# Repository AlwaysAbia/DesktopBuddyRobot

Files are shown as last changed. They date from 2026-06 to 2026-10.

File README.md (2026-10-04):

# Desktop Buddy Robot

A desktop robot with a circular addressable-LED "eye" driven by an ESP32.

The 76-LED display has three modes: the eye animation (default), an a scrolling digital clock (time from NTP) (time from NTP) and a scrolling history of the last 3 messages. The text is tilted 45 degrees so it lines up with the LED grid; rotate the robot about 45 degrees clockwise to read it. The companion app switches modes, eye color and WiFi over Bluetooth LE (GATT layout in [`interface-contract.md`](interface-contract.md)); the eye and Bluetooth work without WiFi. The temporary ThingsBoard RPCs in the same file remain for remote testing.

## Repository layout

| Folder | Contents | Tool |
|---|---|---|
| `BuddyBotFirmware/` | ESP32 firmware (eye animation, WiFi, OTA) | PlatformIO |
| `BuddyRobotDisplay/` | LED display PCB (schematics, layout, libraries, OutJob) | Altium Designer |
| `BuddyRobot3DModel/` | Enclosure CAD and printable STLs | Autodesk Inventor |

Interfaces shared between firmware, the mobile app and the server are documented in
[`interface-contract.md`](interface-contract.md).

## Firmware quick start

1. Install [PlatformIO](https://platformio.org/) (VS Code extension or CLI).
2. Copy `BuddyBotFirmware/include/secrets.example.h` to `BuddyBotFirmware/include/secrets.h` and fill in your ThingsBoard access token and, for the very first boot only, your WiFi credentials (after that WiFi is set over Bluetooth and kept in NVS).
3. From `BuddyBotFirmware/`:
   - Build: `pio run`
   - Flash over USB (first flash / recovery): `pio run -t upload`
   - Over-the-air updates: upload `.pio/build/esp32dev/firmware.bin` as a ThingsBoard OTA package (see `interface-contract.md`, section 3)
   - Serial monitor: `pio device monitor`

## License

MIT, see [LICENSE](LICENSE).

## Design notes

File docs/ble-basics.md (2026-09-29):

# BLE basics for this project

Plain-language notes on the Bluetooth terms that come up when testing the robot.
The exact UUIDs and payloads are in [../interface-contract.md](../interface-contract.md), section 1.

## BLE vs "Bluetooth" in the phone settings

Bluetooth Low Energy (BLE) is a different mode from classic Bluetooth (headphones, speakers,
keyboards). The phone's Bluetooth settings screen mostly handles classic devices. The robot
shows up there because it advertises, but connecting to it needs an app that speaks BLE
(nRF Connect for testing, the companion app later).

## GATT

**GATT** (Generic Attribute Profile) is how a BLE device lays out its data so that any phone can
read and write it.

- A **service** is a group of related values. The robot has one, `9b370000-…`.
- A **characteristic** is one value inside a service that the phone can read, write, or
  subscribe to. The robot has five: WiFi Config, Eye Color, Mode Select, OTA Check Trigger, Status.
- A **UUID** is the long ID that names a service or characteristic. Custom ones like ours have no
  official name, so tools show "Unknown" unless the device also provides a description (the
  robot does, since 0.5.1).
- **Properties** say what the phone may do with a characteristic: Read, Write, Notify.
- **Notify** means the robot pushes a new value to the phone by itself, after the phone has
  subscribed (the triple-arrow button in nRF Connect). Only Status has it.

The robot is the GATT **server** (it holds the data); the phone is the **client** (it asks for
and sets values).

## MTU

**MTU** (Maximum Transmission Unit) is the largest single message a BLE connection carries. Every
connection starts at 23 bytes, which leaves 20 bytes of actual data (3 bytes are protocol
overhead). The phone and robot can agree on a bigger one, and the phone must ask for it:

- nRF Connect on Android: three-dot menu on the connected device, **Request MTU**, enter `247`.
- iOS negotiates it automatically.

Why it matters here: the Status JSON is about 100 bytes and a WiFi Config write can be about
100 bytes. At the default MTU, notifications of that size do not fit. The robot then skips the
notification instead of sending it cut off, so Status only changed when you pressed Read (a Read
is split across several messages automatically). With MTU 247 the notifications arrive.
The companion app must request an MTU of at least 128 right after connecting.

## Pairing

The robot uses "Just Works" pairing: no PIN, and nothing is remembered on the robot. Only the
WiFi Config write asks the phone for an encrypted link, which is why the pairing prompt appears
the first time you write the WiFi credentials.

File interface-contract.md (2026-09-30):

# Interface Contract — Desktop Robot

This is the single source of truth for every interface that crosses a
firmware / mobile app / server boundary. Whenever a Claude Code session
defines or changes a UUID, NVS key, RPC method, or attribute name, **update
this file in the same session**, before finishing. Later sessions (especially
the Flutter app session) are built directly against what's written here.

Keep this file at the repository root (shared by firmware, mobile app and
server) so every session can find it.

---

## 1. BLE GATT Service (Firmware ↔ Mobile App)

**Defined in:** Session D (Phase 2b). Implemented in firmware 0.5.0 (`BuddyBotFirmware/src/ble_control.cpp`).

- Advertised device name: `BuddyBot` (in the scan response). The service UUID is in the advertising packet, so scan by UUID.
- Role: the robot is the GATT peripheral/server; the app is the central. One client at a time; advertising resumes after a disconnect.
- Service UUID: `9b370000-a32f-4baf-8406-88e9298fd20d`

| Characteristic | UUID | Properties | Payload |
|---|---|---|---|
| WiFi Config | `9b370001-a32f-4baf-8406-88e9298fd20d` | Write (encrypted link required) | UTF-8 JSON, see below |
| Eye Color | `9b370002-a32f-4baf-8406-88e9298fd20d` | Read, Write | 1 byte, `0`–`3` |
| Mode Select | `9b370003-a32f-4baf-8406-88e9298fd20d` | Read, Write | 1 byte, `0`–`2` |
| OTA Check Trigger | `9b370004-a32f-4baf-8406-88e9298fd20d` | Write | any payload (even 0 bytes), value ignored |
| Status | `9b370005-a32f-4baf-8406-88e9298fd20d` | Read, Notify | UTF-8 JSON, see below |

Use Write (with response) only; do not use Write Without Response. Each characteristic also has a read-only Characteristic User Description (0x2901) with its name from the first column (added in 0.5.1), so generic tools can label them.

**Pairing / security:** "Just Works" (LE Secure Connections, IO capability none): no PIN, no passkey, **no bonding** (keys are not stored on the robot, so the phone may pair again on each connection). Only WiFi Config demands an encrypted link, so the phone shows its pairing prompt the first time the app writes it; everything else works on an unencrypted link. Just Works protects against passive sniffing, not against a man in the middle. Anyone within radio range can change the eye color or mode and start an OTA check; only WiFi Config needs the encrypted link. Compile-time switch: `BLE_WIFI_CONFIG_REQUIRES_ENCRYPTION` in `ble_config.h`.

**MTU:** the app must negotiate an MTU of at least 128 (Android: `requestMtu(247)` right after connecting; iOS does it automatically) before writing WiFi Config or enabling Status notifications. The robot accepts up to 255. With the default MTU of 23 a Status notification that does not fit is **not sent** (reads are always complete, so the app can fall back to reading).

**Invalid writes are ignored silently.** The BLE stack cannot return an ATT error from the write handler; the reason is logged on the robot's serial port. The app must validate before writing and confirm the effect by reading the value back or watching Status.

### WiFi Config (write)

UTF-8 JSON object, at most 200 bytes:

```json
{"ssid": "MyNetwork", "password": "secret123"}
```

| Field | Type | Rules |
|---|---|---|
| `ssid` | string | Required. 1–32 bytes (UTF-8). An empty string `""` means "forget the stored network": the robot disconnects and stays offline until new credentials arrive. |
| `password` | string | Optional (missing = `""`). Empty for an open network, otherwise 8–63 characters, or exactly 64 hex characters. |

On a valid write the robot stores the credentials in NVS (`wifi/ssid`, `wifi/pass`) and starts connecting in the background, dropping any current WiFi connection at once. It does not reboot. Progress shows in Status `wifi`: `connecting`, then `connected`, or `failed` (with `wifiErr`) after 20 s. While failed, the robot retries every 30 s. New credentials replace the stored ones immediately (there is no "test first" step), so if the app wants to be careful it must re-send the old credentials when it sees `failed`. The password can never be read back.

### Eye Color (read / write)

1 byte, the `eye::Theme` number: `0` = Cyan, `1` = Amber, `2` = Emerald, `3` = Magenta. Applied on the next frame (visible in EYE_ANIMATION) and saved in NVS (`display/eye_theme`). A read returns the current color. Values above `3`, or payloads that are not exactly 1 byte, are ignored.

### Mode Select (read / write)

1 byte: `0` = EYE_ANIMATION, `1` = CURRENT_TIME, `2` = MESSAGE_HISTORY. Applied at once, saved in NVS (`display/mode`) and restored at boot. A read returns the current mode. Values above `2`, or payloads that are not exactly 1 byte, are ignored.

### OTA Check Trigger (write)

Any write starts the same check as the serial command `ota`: the robot asks ThingsBoard which firmware is assigned and installs it if the version differs from the running one. If ThingsBoard is not connected yet the check waits until it is; without WiFi nothing happens. A check already in progress is not restarted. Progress is reported to ThingsBoard (`fw_state`), not over BLE; Status only says whether ThingsBoard is connected (`tb`).

### Status (read / notify)

UTF-8 JSON object, about 100 bytes:

```json
{"wifi":"connected","mode":0,"eye":1,"tb":true,"fw":"0.5.0","heapMinKb":58}
```

| Field | Type | Meaning |
|---|---|---|
| `wifi` | string | `none` (no credentials stored), `connecting`, `connected`, `failed` |
| `wifiErr` | string | Only present while `wifi` is `failed`: `not_found` (network not seen), `auth` (wrong password or handshake failed), `other` |
| `mode` | number | Current mode, as in Mode Select |
| `eye` | number | Current eye color, as in Eye Color |
| `tb` | bool | ThingsBoard MQTT connection is up |
| `fw` | string | Running firmware version (`FIRMWARE_VERSION`) |
| `heapMinKb` | number | Lowest free heap since boot, in KB (diagnostic) |

Notified (if the app subscribed) whenever `wifi`, `mode`, `eye` or `tb` changes, and after **every** write to any writable characteristic above (valid or not), so the app can also use a write plus its notification as a round-trip probe. Reading Status always returns the current state. New fields may be added later, so the app must ignore fields it does not know.

**Offline requirement (decided 2026-09-29):** the robot must work with no WiFi and no internet. The eye animation runs at boot without waiting for WiFi, and BLE Eye Color and Mode Select work fully offline (BLE never depends on WiFi or ThingsBoard). There is **no offline messaging**: messages come only from ThingsBoard (Phase 4). BLE uses NimBLE (NimBLE-Arduino 2.3.7), not Bluedroid.

**Shared radio:** the ESP32 has one radio for WiFi and BLE. While a BLE client is connected the robot puts WiFi into modem sleep (`BLE_WIFI_SLEEP_WHILE_CONNECTED` in `ble_config.h`) so BLE gets air time, and back to always-awake when the client disconnects. Expect a slightly slower ThingsBoard connection during a BLE session. Coexistence was **not verified on hardware** in Session D (no hardware access): see its test plan.

---

## 2. NVS Keys (Firmware persistence)

**Defined in:** Sessions C & D

| Namespace | Key | Type | Purpose |
|---|---|---|---|
| `ota` | `pending` | string | Firmware version an OTA update just started flashing. Written before the download, cleared on the next boot. |
| `ota` | `bad` | string | Version that was flashed but didn't boot (rolled back). Checks skip it (and report `FAILED`); `ota force` overrides. Cleared when an update succeeds. |
| `msgs` | `m0` | string | Newest stored message (max 100 chars). Missing key = empty slot. |
| `msgs` | `m1` | string | Second newest message. |
| `msgs` | `m2` | string | Oldest of the 3 stored messages. A new message shifts `m0`→`m1`→`m2` and drops the old `m2`. |

Added in Session D (firmware 0.5.0):

| Namespace | Key | Type | Purpose |
|---|---|---|---|
| `wifi` | `ssid` | string | Stored WiFi network name, empty = forgotten. **Missing key = genuinely first-ever boot**: the firmware then seeds `ssid` / `pass` from `WIFI_SSID` / `WIFI_PASSWORD` in `secrets.h` (may be empty) and never reads `secrets.h` again. Erased NVS therefore falls back to those build-time values once. |
| `wifi` | `pass` | string | Stored WiFi password (plain text; NVS encryption is not enabled). |
| `display` | `eye_theme` | u8 | Last selected eye color (`eye::Theme` number). Written when it changes, read at boot. Missing key = Amber (boot default). |
| `display` | `mode` | u8 | Last selected display mode (`modes::Mode` number). Written when it changes (BLE, RPC `nextMode`), restored at boot. Missing key = `0` (eye). |
| `time` | `last` | u64 | Last known Unix time (seconds, UTC). Saved at the first NTP sync after boot and every 30 minutes after that. At boot without WiFi the clock starts from it and counts on the ESP32's internal ticks, so it stays roughly right offline. Time while the robot was unpowered is not counted, and internal ticks drift; the next NTP sync corrects both. |

Display modes (firmware `modes::Mode`, same numbers as BLE Mode Select): `0` = `EYE_ANIMATION`, `1` = `CURRENT_TIME`, `2` = `MESSAGE_HISTORY`. Boot mode is the persisted one (`display/mode`), `EYE_ANIMATION` on the first boot. Eye color themes (`eye::Theme`): `0` = Cyan, `1` = Amber (boot default), `2` = Emerald, `3` = Magenta.

---

## 3. ThingsBoard Integration (Firmware ↔ Server)

**Defined in:** Sessions B & F

- Server: ThingsBoard Cloud EU, host `eu.thingsboard.cloud` (self-hosted CE planned later: same protocol, just a host/token swap)
- Transport: MQTT over TLS, port `8883`, server cert checked against the ESP32 core's built-in Mozilla root CA bundle. One persistent connection (`BuddyBotFirmware/src/tb_client.cpp`) carries OTA now and messaging later.
- Host/port in firmware: `TB_HOST` / `TB_PORT` in `BuddyBotFirmware/include/thingsboard_config.h`
- Device profile name: `BuddyBot`
- Device name: `buddybot-01`
- Access token: `TB_ACCESS_TOKEN` in `BuddyBotFirmware/include/secrets.h` (gitignored; template in `secrets.example.h`). Never committed.
- Attributes:
  - Firmware version reported as: client attributes `current_fw_title` / `current_fw_version`, sent on every (re)connect. The same two keys are also sent as telemetry, because ThingsBoard's OTA dashboard reads them from there.
  - OTA state reported as telemetry `fw_state` (`DOWNLOADING` → `DOWNLOADED` → `UPDATING` → `UPDATED`, or `FAILED`) plus `fw_error`. `UPDATED` / `FAILED` (for a rollback) is sent after the reboot, on the first connect.
  - OTA-availability push attribute: none of our own. ThingsBoard sets the shared attributes `fw_title`, `fw_version`, `fw_size`, `fw_checksum`, `fw_checksum_algorithm` when a package is assigned. The device reads them only when a check runs (boot or serial `ota`), so it does not auto-update on assignment yet.
- Device status (firmware 0.6.0, `BuddyBotFirmware/src/remote_ops.cpp`), sent on every (re)connect:
  - Client attributes, resent whenever they change (checked every 5 s): `ota_partition` (running slot, `app0`/`app1`), `ota_image_state` (`NEW`, `PENDING_VERIFY`, `VALID`, `INVALID`, `ABORTED`, `UNDEFINED`, `n/a`), `ota_rollback_possible` (bool), `ota_awaiting_confirm` (bool, true while a new image has not yet connected to ThingsBoard), `ota_bad_version` (`-` = none), `ota_last_error` (`-` = none; cleared by a successful update).
  - Also client attributes (0.6.1): `mode` (`EYE_ANIMATION`, `CURRENT_TIME`, `MESSAGE_HISTORY`), `eye_color` (`Cyan`, `Amber`, `Emerald`, `Magenta`), `msg_count` (0-3), `msg_latest` (newest stored message, `-` = none).
  - Telemetry, every 60 s: `rssi` (dBm), `uptime_s`, `heap_free_kb`, `heap_min_kb`.
- Rollback confirmation (0.6.0): a freshly OTA-installed image is **not** marked valid at boot. It is confirmed at the first successful ThingsBoard connection (`ota_image_state` goes `PENDING_VERIFY` → `VALID`). If that does not happen within `OTA_CONFIRM_TIMEOUT_S` (300 s) of boot, or the robot resets first, the bootloader rolls back to the previous firmware and the failed version is flagged `ota/bad`.
- RPC methods:
  - `checkForUpdate` (0.6.0, permanent): params `{"force": true}` (optional; a plain `true` also works). Same as serial `ota` / `ota force`. Responds `{"accepted": <bool>, "force": <bool>}`; `accepted: false` means a check or update was already running. Progress is the `fw_state` telemetry.
  - Kept on purpose (decided 2026-09-30): these RPCs (`BuddyBotFirmware/src/remote_test.cpp`, still named "test" in the code) are the way messages reach the robot, so there is no separate messaging method. Two-way (`nextMode`, `clearMessages`, `reboot` take no params):
    - `nextMode`: switches to the next display mode.
    - `clearMessages`: deletes the stored message history (RAM + NVS `msgs/*`).
    - `addMessage`: params `{"text": "..."}` (or a plain JSON string); stores it as the newest message (max 100 chars). CR / LF characters are removed; a message that is empty after that is ignored.
    - `reboot`: restarts the device ~1.5 s after responding.
    - All four respond `{"mode": "<EYE_ANIMATION|CURRENT_TIME|MESSAGE_HISTORY>", "timeSynced": <bool>, "messages": <0-3>}` (state after the action).
- OTA package naming convention:
  - Package **Title** = `BuddyBot` (must equal `FIRMWARE_TITLE` in `BuddyBotFirmware/include/ota_config.h`; the device rejects other titles)
  - Package **Version** = `FIRMWARE_VERSION` of the build, `MAJOR.MINOR.PATCH`
  - Package type Firmware, device profile `BuddyBot`, binary = `BuddyBotFirmware/.pio/build/esp32dev/firmware.bin`, checksum MD5 or SHA-256 (auto-generated is fine)
  - Install rule: installs the assigned version if it differs from the running one (downgrades allowed), unless it is the NVS `ota/bad` version
- Serial commands (115200 baud): `ota`, `ota force`, `status`, plus `msg clear` (same as the RPC above). The serial `mode` command was removed in 0.5.0: the app switches modes over BLE. The RPC `nextMode` stays

---

## Change log

| Session | Date | What changed |
|---|---|---|
| B (Stage 1) | 2026-09-28 | Added NVS keys `ota/pending` and `ota/bad`; added section 4 (pull-OTA manifest format) |
| B (Stage 2) | 2026-09-28 | Filled in section 3 (ThingsBoard host, profile `BuddyBot`, device `buddybot-01`, token location, `current_fw_*` attributes, OTA package naming). Removed section 4 (pull-OTA manifest), replaced by ThingsBoard OTA. NVS `ota/*` keys now used by ThingsBoard OTA. |
| C (Phase 2a) | 2026-09-29 | Added NVS keys `msgs/m0`..`msgs/m2` (message history), display mode and eye theme numbering, TEMPORARY test RPCs `nextMode` / `clearMessages` and serial `mode` / `msg clear`. |
| C (Phase 2a fixes) | 2026-09-29 | TEMPORARY RPCs `addMessage` (params `{"text"}`) and `reboot` added for remote testing. Display: clock and text use an even-pitch LED map, `SCREEN_Y_SIGN` -1, text tilted 45 degrees (`TEXT_ROTATION_DEG`) with a 5x7 font; RPC method/response-field limits raised to 8. |
| C (close-out) | 2026-09-29 | Recorded the offline requirement (eye at boot without WiFi, BLE mode/color offline, no offline messages, NimBLE) and the decided NVS keys `display/eye_theme` and `time/last` (not implemented yet). |
| D (Phase 2b) | 2026-09-29 | Defined the BLE GATT service (section 1: service and 5 characteristic UUIDs, payload formats, security, MTU, Status JSON). NVS keys `wifi/ssid`, `wifi/pass`, `display/eye_theme`, `display/mode`, `time/last` implemented. WiFi now connects in the background from NVS credentials (seeded from `secrets.h` on the first-ever boot only). Serial `mode` command removed. |
| D (0.5.1) | 2026-09-29 | Added a Characteristic User Description (0x2901) to each BLE characteristic. No UUID or payload change. |
| Remote operation | 2026-09-30 | Firmware 0.6.0: RPC `checkForUpdate`, client attributes `ota_*` and telemetry `rssi` / `uptime_s` / `heap_*` (section 3), and rollback confirmation moved to the first ThingsBoard connection with a 300 s timeout. No BLE change. |
| Remote operation (0.6.1) | 2026-09-30 | Client attributes `mode`, `eye_color`, `msg_count`, `msg_latest` (section 3). |

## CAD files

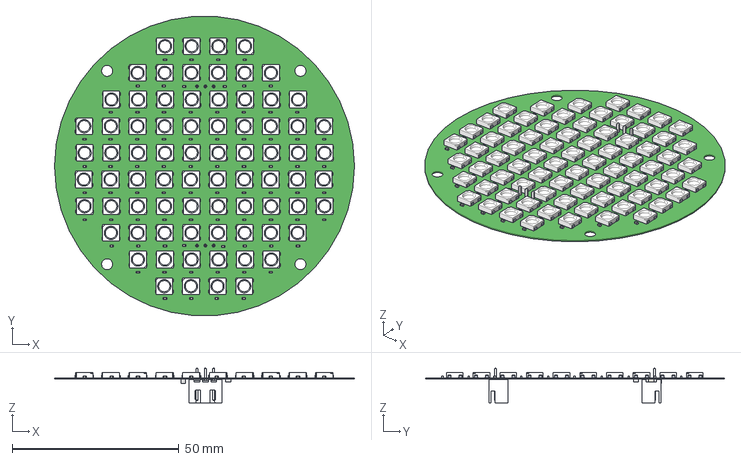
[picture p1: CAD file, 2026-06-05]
BuddyRobot3DModel/Display.step
90.0 x 89.7 x 10.4 mm

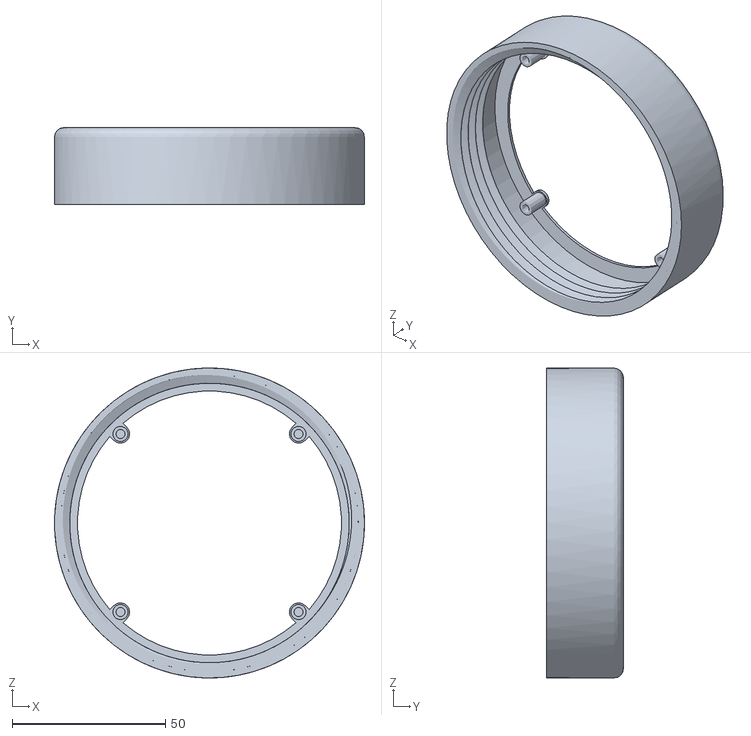
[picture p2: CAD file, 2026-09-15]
BuddyRobot3DModel/STL/DisplayCoverUpdated.stl
101.0 x 25.0 x 101.0

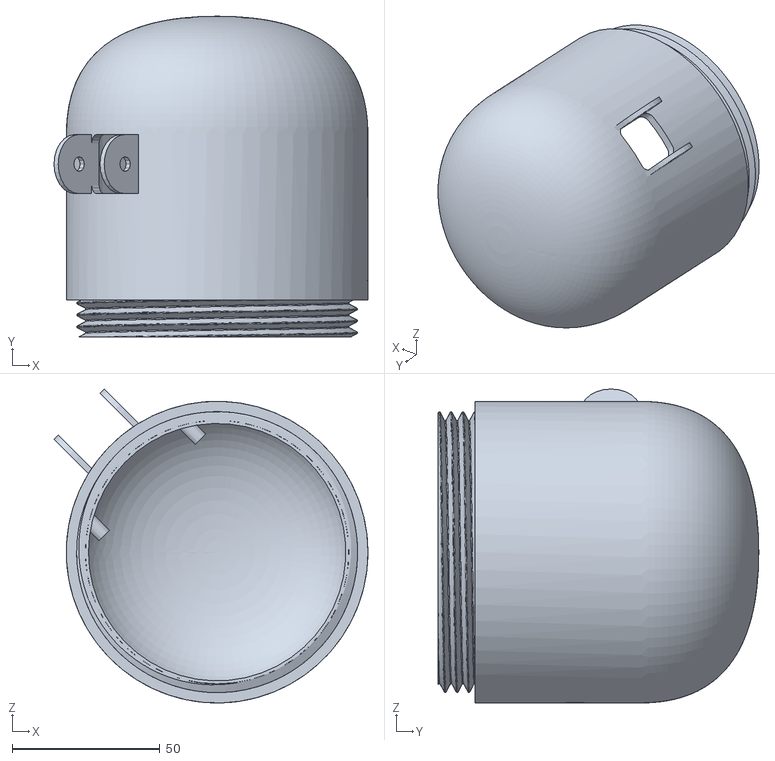
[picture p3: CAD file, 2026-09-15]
BuddyRobot3DModel/STL/HeadUpdated.stl
106.2 x 108.4 x 106.1

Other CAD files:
BuddyRobot3DModel/BuddyRobotASM.iam
BuddyRobot3DModel/BuddyRobotBase.ipt
BuddyRobot3DModel/BuddyRobotBaseDoor.ipt
BuddyRobot3DModel/Display/Display/Display.iam
BuddyRobot3DModel/Display/Display/Open CASCADE STEP translator 7.5 1.ipt
BuddyRobot3DModel/Display/Display/Open CASCADE STEP translator 7.5 10.ipt
BuddyRobot3DModel/Display/Display/Open CASCADE STEP translator 7.5 100.ipt
BuddyRobot3DModel/Display/Display/Open CASCADE STEP translator 7.5 101.ipt
BuddyRobot3DModel/Display/Display/Open CASCADE STEP translator 7.5 102.ipt
BuddyRobot3DModel/Display/Display/Open CASCADE STEP translator 7.5 103.ipt
BuddyRobot3DModel/Display/Display/Open CASCADE STEP translator 7.5 104.ipt
BuddyRobot3DModel/Display/Display/Open CASCADE STEP translator 7.5 105.ipt
BuddyRobot3DModel/Display/Display/Open CASCADE STEP translator 7.5 106.ipt
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

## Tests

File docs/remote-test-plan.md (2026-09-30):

# Remote test plan (ThingsBoard dashboard only)

For firmware 0.6.0 and later. No serial, no USB. Device: `buddybot-01`. RPCs are sent from a
dashboard RPC widget or the device's "RPC" tab (two-way). Keys are in
[../interface-contract.md](../interface-contract.md), section 3.

Done and confirmed on the robot (2026-09-30):
- Status attributes and telemetry (0.6.0), the `checkForUpdate` RPC (with and without `force`).
- Mode, eye color and message attributes (0.6.1), including after `reboot`.
- Timeout rollback: a build with `OTA_TEST_SKIP_CONFIRM 1` stayed unconfirmed, rolled back to the
  previous version after about 5 minutes, was flagged as `ota_bad_version`, and was not downloaded
  again by a plain `checkForUpdate`.

## Repeat this test for any change to the OTA or rollback code

1. Set `OTA_TEST_SKIP_CONFIRM 1` and a version above the running one in `ota_config.h` (do not commit it).
   Build, upload, assign.
2. `checkForUpdate` with `{}`. After the reboot: `ota_awaiting_confirm` true, `ota_image_state`
   `PENDING_VERIFY`, and it stays that way although the robot is online. Do not reboot it by hand
   (a reset rolls back at once through the bootloader, which is a different path).
3. After about 5 minutes (`uptime_s` near 300) the robot restarts on the previous version:
   `fw_state` `FAILED`, `ota_bad_version` = the test version, `ota_last_error` mentions the rollback.
4. `checkForUpdate` with `{}` must not reinstall it. `{"force": true}` does.
5. Restore `ota_config.h` (`git checkout`) and confirm a normal build reaches `VALID`.

## Safety notes

- A broken WiFi or ThingsBoard connection in a new build causes a rollback after 5 minutes;
  a router that is off for more than 5 minutes right after an update also causes one (the version is
  then flagged bad and needs a higher version number).
- A download that is interrupted (reboot or a second check while it runs) also flags that version bad.
  `checkForUpdate` with `{"force": true}` retries it.

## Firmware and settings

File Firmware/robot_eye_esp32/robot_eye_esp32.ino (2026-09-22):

#include <FastLED.h>
#include <math.h>
#include <WiFi.h>
#include <ESPmDNS.h>
#include <WiFiUdp.h>
#include <ArduinoOTA.h>

// ==========================================
// WI-FI & OTA CONFIGURATION
// ==========================================
const char* ssid     = ""; 
const char* password = "";     
const char* otaHost  = "ESP32-SciFi-Eye";

// ==========================================
// HARDWARE & FASTLED CONFIGURATION
// ==========================================
#define DATA_PIN     16   // GPIO 16
#define NUM_LEDS     76
#define BRIGHTNESS   120
#define FPS          60

CRGB leds[NUM_LEDS];

struct Point2D {
  float x; // Horizontal in Visual Space
  float y; // Vertical in Visual Space
};

Point2D ledCoords[NUM_LEDS];

const int NUM_ROWS = 10;
const int rowLengths[NUM_ROWS] = {4, 6, 8, 10, 10, 10, 10, 8, 6, 4};
const bool IS_SERPENTINE = true; 

void buildCoordinateMap() {
  int ledIndex = 0;

  // Rotated angle (-135.0f) for matrix alignment
  const float rad = -135.0f * (M_PI / 180.0f); 
  const float cosA = cosf(rad);
  const float sinA = sinf(rad);

  for (int r = 0; r < NUM_ROWS; r++) {
    int count = rowLengths[r];
    float rawY = 1.0f - (2.0f * (r + 0.5f) / (float)NUM_ROWS);

    for (int c = 0; c < count; c++) {
      // Handle serpentine / zigzag row wiring direction
      int colIndex = (IS_SERPENTINE && (r % 2 != 0)) ? (count - 1 - c) : c;

      float rawX = -1.0f + (2.0f * (colIndex + 0.5f) / (float)count);

      rawX *= 0.95f;
      rawY *= 0.95f;

      // Rotational matrix transform
      float rotatedX = rawX * cosA - rawY * sinA;
      float rotatedY = rawX * sinA + rawY * cosA;

      ledCoords[ledIndex].x = rotatedX;
      ledCoords[ledIndex].y = rotatedY;

      ledIndex++;
    }
  }
}

// ==========================================
// COLOR PALETTES & ANIMATION STATES
// ==========================================
struct EyePalette {
  CRGB irisCore;
  CRGB irisEdge;
  CRGB eyelidEdge;
};

// ACTIVE PALETTE: Amber / Orange
const EyePalette AMBER_THEME = { CRGB(255, 140, 0), CRGB(120, 20, 0), CRGB(255, 200, 100) };

/* OTHER PALETTES (SAVED FOR FUTURE USE):
const EyePalette THEMES[4] = {
  { CRGB(0, 255, 255), CRGB(0, 30, 120), CRGB(180, 255, 255) }, // Cyan
  { CRGB(255, 140, 0), CRGB(120, 20, 0),  CRGB(255, 200, 100) }, // Amber
  { CRGB(0, 255, 100), CRGB(0, 80, 20),   CRGB(150, 255, 180) }, // Emerald
  { CRGB(255, 0, 150), CRGB(80, 0, 80),   CRGB(255, 160, 220) }  // Magenta
};
uint8_t currentTheme = 0;
unsigned long lastThemeChange = 0;
*/

float currentPupilX = 0.0f, currentPupilY = 0.0f;
float targetPupilX  = 0.0f, targetPupilY  = 0.0f;

unsigned long lastGazeChange = 0;
unsigned long gazeInterval   = 2000;

enum BlinkState { IDLE, CLOSING, CLOSED, OPENING };
BlinkState blinkState = IDLE;
float blinkProgress   = 0.0f;
unsigned long lastBlinkCheck = 0;
unsigned long nextBlinkTime  = 3000;

void updateGazeTarget() {
  if (millis() - lastGazeChange > gazeInterval) {
    float angle = (random(0, 360) * M_PI) / 180.0f;
    float dist  = (random(0, 100) / 100.0f) * 0.40f; 
    
    targetPupilX = cosf(angle) * dist;
    targetPupilY = sinf(angle) * dist;

    gazeInterval   = random(1200, 3500);
    lastGazeChange = millis();
  }

  currentPupilX += (targetPupilX - currentPupilX) * 0.08f;
  currentPupilY += (targetPupilY - currentPupilY) * 0.08f;
}

void updateBlinkAnimation() {
  unsigned long now = millis();

  switch (blinkState) {
    case IDLE:
      if (now - lastBlinkCheck > nextBlinkTime) {
        blinkState    = CLOSING;
        lastBlinkCheck = now;
      }
      break;

    case CLOSING:
      blinkProgress += 0.12f;
      if (blinkProgress >= 1.0f) {
        blinkProgress = 1.0f;
        blinkState    = CLOSED;
        lastBlinkCheck = now;
      }
      break;

    case CLOSED:
      if (now - lastBlinkCheck > 60) {
        blinkState = OPENING;
      }
      break;

    case OPENING:
      blinkProgress -= 0.10f;
      if (blinkProgress <= 0.0f) {
        blinkProgress  = 0.0f;
        blinkState     = IDLE;
        lastBlinkCheck = now;
        nextBlinkTime  = random(2000, 6000);
      }
      break;
  }
}

void renderEyeFrame() {
  /* AUTOMATIC THEME SWITCHING (COMMENTED OUT FOR NOW)
  if (millis() - lastThemeChange > 5000) {
    currentTheme = (currentTheme + 1) % 4;
    lastThemeChange = millis();
  }
  const EyePalette& theme = THEMES[currentTheme];
  */

  const EyePalette& theme = AMBER_THEME; 

  const float pupilRadius = 0.28f;
  const float irisRadius  = 1.05f; 

  const float glint1X = currentPupilX + 0.10f;
  const float glint1Y = currentPupilY + 0.10f;
  const float glint2X = currentPupilX - 0.08f;
  const float glint2Y = currentPupilY - 0.08f;

  float eyelidCutoffY = (1.0f - blinkProgress) * 0.95f;

  for (int i = 0; i < NUM_LEDS; i++) {
    float x = ledCoords[i].x;
    float y = ledCoords[i].y;

    // Eyelid horizontal cutoff
    float absY = fabsf(y);
    if (absY >= eyelidCutoffY) {
      leds[i] = CRGB::Black;

      if (absY < eyelidCutoffY + 0.20f && blinkProgress > 0.05f) {
        leds[i] = theme.eyelidEdge;
        leds[i].nscale8(200);
      }
      continue;
    }

    if (blinkProgress >= 0.92f && absY < 0.18f) {
      leds[i] = theme.eyelidEdge;
      continue;
    }

    // Radial rendering
    float dx = x - currentPupilX;
    float dy = y - currentPupilY;
    float distToPupil = sqrtf(dx * dx + dy * dy);

    // Primary Specular Glint
    float dGlint1 = sqrtf((x - glint1X) * (x - glint1X) + (y - glint1Y) * (y - glint1Y));
    if (dGlint1 < 0.08f) {
      leds[i] = CRGB::White;
      continue;
    }

    // Secondary Specular Glint
    float dGlint2 = sqrtf((x - glint2X) * (x - glint2X) + (y - glint2Y) * (y - glint2Y));
    if (dGlint2 < 0.05f) {
      leds[i] = CRGB(180, 180, 180);
      continue;
    }

    // Pupil
    if (distToPupil <= pupilRadius) {
      leds[i] = CRGB::Black;
    } 
    // Iris
    else if (distToPupil <= irisRadius) {
      float t = (distToPupil - pupilRadius) / (irisRadius - pupilRadius);
      t = constrain(t, 0.0f, 1.0f);

      CRGB color = blend(theme.irisCore, theme.irisEdge, uint8_t(t * 255.0f));

      if (t > 0.85f) {
        float rimFactor = (1.0f - t) / 0.15f;
        color.nscale8(uint8_t(rimFactor * 255.0f));
      }

      leds[i] = color;
    } 
    else {
      leds[i] = CRGB::Black;
    }
  }
}

// Helper function to translate status codes into text
const char* getWiFiStatusName(wl_status_t status) {
  switch (status) {
    case WL_IDLE_STATUS:     return "IDLE_STATUS";
    case WL_NO_SSID_AVAIL:   return "NO_SSID_AVAIL (SSID not found)";
    case WL_SCAN_COMPLETED:  return "SCAN_COMPLETED";
    case WL_CONNECTED:       return "CONNECTED";
    case WL_CONNECT_FAILED:  return "CONNECT_FAILED (Wrong password/Security mismatch)";
    case WL_CONNECTION_LOST: return "CONNECTION_LOST";
    case WL_DISCONNECTED:    return "DISCONNECTED";
    default:                 return "UNKNOWN";
  }
}

// ==========================================
// OTA & WI-FI INITIALIZATION WITH LOGGING
// ==========================================
void setupOTA() {
  Serial.begin(115200);
  delay(200);
  Serial.println("\n==========================================");
  Serial.println("   ESP32 Sci-Fi Robot Eye Booting");
  Serial.println("==========================================");

  // 1. Fully disconnect and clear lingering state
  WiFi.disconnect(true);
  delay(100);

  // 2. Configure Station Mode & Disable Modem Sleep
  WiFi.persistent(false);
  WiFi.mode(WIFI_STA);
  WiFi.setSleep(false); // Prevents dropouts on Android hotspots

  Serial.print("[WiFi] Attempting connection to SSID: ");
  Serial.println(ssid);

  WiFi.begin(ssid, password);

  // 3. Connection Handshake Loop with Detailed Debug Prints
  int attempts = 0;
  while (WiFi.status() != WL_CONNECTED && attempts < 40) { // 20-second window
    delay(500);
    Serial.print(".");
    
    // Print current status code every 5 seconds
    if (attempts > 0 && attempts % 10 == 0) {
      Serial.printf("\n[WiFi Handshake Status]: %s\n", getWiFiStatusName(WiFi.status()));
    }
    attempts++;
  }

  // 4. Verify Connection Result
  if (WiFi.status() == WL_CONNECTED) {
    Serial.println("\n\n[WiFi] CONNECTION SUCCESSFUL!");
    Serial.print("[WiFi] IP Address: ");
    Serial.println(WiFi.localIP());
    Serial.print("[WiFi] Signal Strength (RSSI): ");
    Serial.print(WiFi.RSSI());
    Serial.println(" dBm");

    // Configure ArduinoOTA
    ArduinoOTA.setHostname(otaHost);

    ArduinoOTA.onStart([]() {
      Serial.println("[OTA] Firmware update starting...");
      FastLED.clear(true);
    });

    ArduinoOTA.onEnd([]() {
      Serial.println("\n[OTA] Update Complete! Rebooting...");
    });

    ArduinoOTA.onProgress([](unsigned int progress, unsigned int total) {
      Serial.printf("[OTA] Progress: %u%%\r", (progress / (total / 100)));
    });

    ArduinoOTA.onError([](ota_error_t error) {
      Serial.printf("[OTA] Error[%u]: ", error);
      if (error == OTA_AUTH_ERROR) Serial.println("Auth Failed");
      else if (error == OTA_BEGIN_ERROR) Serial.println("Begin Failed");
      else if (error == OTA_CONNECT_ERROR) Serial.println("Connect Failed");
      else if (error == OTA_RECEIVE_ERROR) Serial.println("Receive Failed");
      else if (error == OTA_END_ERROR) Serial.println("End Failed");
    });

    ArduinoOTA.begin();
    Serial.println("[OTA] Service initialized and listening for updates.");
  } else {
    Serial.println("\n\n[WiFi] CONNECTION FAILED!");
    Serial.printf("[WiFi] Final Reason: %s\n", getWiFiStatusName(WiFi.status()));
    Serial.println("[WiFi] Proceeding to run animation in OFFLINE mode.");
  }
  Serial.println("==========================================\n");
}

// ==========================================
// MAIN SETUP & LOOP
// ==========================================
void setup() {
  // Initialize FastLED (LEDs remain OFF during WiFi setup to prevent brownout)
  FastLED.addLeds<WS2812B, DATA_PIN, GRB>(leds, NUM_LEDS);
  FastLED.setBrightness(BRIGHTNESS);
  FastLED.clear(true);

  // Pre-calculate 2D matrix map
  buildCoordinateMap();

  // Initialize WiFi and OTA
  setupOTA();
}

void loop() {
  // Check for wireless updates
  ArduinoOTA.handle();

  // Run render pipeline
  updateGazeTarget();
  updateBlinkAnimation();
  renderEyeFrame();

  FastLED.show();
  FastLED.delay(1000 / FPS);
}

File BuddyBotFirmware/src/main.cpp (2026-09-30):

#include <Arduino.h>
#include <FastLED.h>

#include "ble_control.h"
#include "clock_mode.h"
#include "display_modes.h"
#include "eye_mode.h"
#include "led_matrix.h"
#include "messages.h"
#include "ota_config.h"
#include "ota_update.h"
#include "remote_ops.h"
#include "remote_test.h"
#include "tb_client.h"
#include "wifi_manager.h"

// ==========================================
// WI-FI + BLE
// WiFi credentials come from NVS and connect in the background (src/wifi_manager.cpp);
// the app sets them over BLE (src/ble_control.cpp). Firmware updates come only from
// ThingsBoard OTA (src/ota_update.cpp); USB upload is the recovery path.
// ==========================================

// ==========================================
// LED PANEL & DISPLAY MODES
// Pin / LED count / brightness / FPS: include/led_matrix.h
// Modes (eye, clock, message history): include/display_modes.h
// ==========================================

// ==========================================
// BUZZER SELF-TEST (Phase 0 bring-up)
// DISABLED: no sound on GPIO32/33/25/26 during bring-up. Buzzer hardware is
// suspect and the actual pin is unconfirmed. Re-enable once that is resolved.
// ==========================================
#define BUZZER_SELFTEST     0
#define BUZZER_PIN          32   // UNCONFIRMED - see note above
#define BUZZER_ACTIVE_HIGH  1    // Active buzzer driven directly / via NPN. Set 0 for active-low (PNP) modules.

#if BUZZER_SELFTEST
// 3 short beeps. Active buzzer: plain on/off, no PWM.
void buzzerSelfTest() {
  const uint8_t onLevel  = BUZZER_ACTIVE_HIGH ? HIGH : LOW;
  const uint8_t offLevel = BUZZER_ACTIVE_HIGH ? LOW : HIGH;

  pinMode(BUZZER_PIN, OUTPUT);
  digitalWrite(BUZZER_PIN, offLevel);

  for (int i = 0; i < 3; i++) {
    digitalWrite(BUZZER_PIN, onLevel);
    delay(80);
    digitalWrite(BUZZER_PIN, offLevel);
    delay(120);
  }
}
#endif

// ==========================================
// SERIAL COMMANDS
//   ota        - install the package assigned in ThingsBoard if it differs
//   ota force  - same, even if that version failed to boot before
//   status     - print version / partition / rollback / ThingsBoard state
//   msg clear  - TEMPORARY: delete the stored message history
// "msg clear" is a TEMPORARY test placeholder until Phase 4 messaging exists.
// It and the mode switch are also available remotely as the RPCs in remote_test.cpp;
// the app switches modes over BLE.
// ==========================================
void handleSerialCommands() {
  static String line;
  while (Serial.available()) {
    char c = (char)Serial.read();
    if (c != '\n' && c != '\r') {
      if (line.length() < 32) line += c;
      continue;
    }
    line.trim();
    if (line == "ota")            ota::requestCheck(false);
    else if (line == "ota force") ota::requestCheck(true);
    else if (line == "status")    ota::printStatus();
    else if (line == "msg clear") messages::clear();      // TEMPORARY, see above
    else if (line.length())       Serial.println("Commands: ota | ota force | status | msg clear");
    line = "";
  }
}

// ==========================================
// MAIN SETUP & LOOP
// ==========================================
void setup() {
  Serial.begin(115200);
  delay(200);
  Serial.println("\r\n==========================================");
  Serial.printf("   ESP32 Sci-Fi Robot Eye Booting (%s %s)\r\n", FIRMWARE_TITLE, FIRMWARE_VERSION);
  Serial.println("==========================================");

  // Initialize FastLED + coordinate map
  led_matrix::begin();

#if BUZZER_SELFTEST
  buzzerSelfTest();
#endif

  // Rollback safety: an image freshly installed by OTA (either path) must
  // confirm itself, or the bootloader reverts it on the next reset.
  // Keep this early in setup().
  ota::confirmRunningFirmware();
  ota::printStatus();

  // Restore the saved eye color, clock time, message history and display mode.
  eye::begin();
  clock_mode::begin();
  messages::begin();
  modes::begin();

  // WiFi connects in the background: the eye is up right away, with or without WiFi.
  // BLE (mode, color, WiFi provisioning) works either way.
  wifi_mgr::begin();
  ble_control::begin();

  // ThingsBoard connects from loop(); the boot check waits for it.
  ota::begin();
  remote_ops::begin();   // checkForUpdate RPC, status reporting
  remote_test::begin();  // TEMPORARY mode/message test RPCs
#if OTA_CHECK_ON_BOOT
  ota::requestCheck(false);
#endif
}

void loop() {
  wifi_mgr::loop();
  ble_control::loop();  // also during OTA downloads, so the app stays responsive

  // ThingsBoard connection + OTA check
  tb_client::loop();
  ota::loop();
  remote_ops::loop();
  clock_mode::loop();  // starts NTP once WiFi is up
  remote_test::loop();
  handleSerialCommands();

  // While a ThingsBoard firmware download is running, keep the eye dark
  // (lower current while flash is written) and skip the frame delay so chunks
  // are requested back-to-back.
  static bool blanked = false;
  if (ota::isUpdating()) {
    if (!blanked) {
      FastLED.clear(true);
      blanked = true;
    }
    delay(1);
    return;
  }
  blanked = false;

  // Run render pipeline for the current mode
  modes::render();

  FastLED.show();
  FastLED.delay(1000 / FPS);
}

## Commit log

2026-06-04 Laid out board, Routing Time
    [BuddyRobotDisplay.PrjPcb, Capacitors.SchDoc, LEDs.SchDoc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]
2026-06-04 Finished PCB - fih
    [PCB.PcbDoc]
2026-06-05 Added Outjob and Libs
    [BuddyRobotDisplay.PrjPcb, Connectors.PcbLib, Connectors.SchLib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]
2026-06-05 Add 3D Models Current State
    [BuddyRobotASM.iam, Display.iam, Display.step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]
2026-09-15 Updated new version
    [BuddyRobotASM.iam, DisplayCover.ipt, DisplayCoverUpdated.stl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]
2026-09-22 Added base firmware V1.0
    [BuddyRobotASM.iam, BuddyRobotBase.ipt, BuddyRobotBaseDoor.ipt]
2026-09-23 Migrate firmware from Arduino IDE sketch to PlatformIO
    Move Firmware/robot_eye_esp32/robot_eye_esp32.ino to
    BuddyBotFirmware/src/main.cpp with identical eye animation, WiFi and
    ArduinoOTA logic.
    - Target esp32dev (generic WROOM-32) on pioarduino 54.03.20, which ships
    arduino-esp32 3.2.0, the same core the Arduino IDE used
    - Pin FastLED to 3.9.16 (the version installed in the Arduino IDE)
    - Match Arduino "ESP32 Dev Module" defaults: QIO, 80 MHz flash,
    default.csv partitions
    - Add esp32dev_ota env for uploading over ArduinoOTA
    - Move WiFi credentials to gitignored include/secrets.h
    (template: include/secrets.example.h)
    - Add BUZZER_SELFTEST: 3 short beeps on boot on GPIO 32
    Co-Authored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
    [main.cpp]
2026-09-28 Add temporary buzzer pin scan (GPIO32/33/25/26)
    Buzzer did not sound on GPIO32. Scan candidate pins at boot, beep count
    = position in list. GPIO34/35 excluded: input-only on ESP32.
    [main.cpp]
2026-09-28 Disable buzzer self-test; remove temporary pin scan
    No sound on GPIO32/33/25/26. Buzzer hardware is suspect and the real
    pin is unconfirmed, so the self-test is off (BUZZER_SELFTEST 0) until
    that is resolved.
    [main.cpp]
2026-09-28 Add rollback-safe HTTPS pull OTA alongside ArduinoOTA
    - New src/ota_update.cpp: fetch a JSON manifest (version/url/md5) over
    http or https (verified against the core's built-in CA bundle), compare
    semver against FIRMWARE_VERSION, flash via Update.h and reboot.
    - Rollback: override verifyRollbackLater() so the core no longer
    auto-confirms OTA images before setup(); setup() confirms explicitly.
    NVS ota/pending + ota/bad stop a rolled-back version being re-fetched.
    - Triggers: boot-time check (OTA_CHECK_ON_BOOT) and serial commands
    "ota", "ota force", "status". ArduinoOTA push is kept.
    - include/ota_config.h holds FIRMWARE_VERSION, OTA_MANIFEST_URL and a
    test-only crash switch for e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
    [main.cpp, ota_update.cpp]
2026-09-28 Switch to min_spiffs partition table for larger OTA slots
    App image was at 93.5% of default.csv's 1.25MB slot; ThingsBoard SDK and
    BLE won't fit. min_spiffs.csv keeps two OTA slots + otadata (rollback
    unaffected) at 1.875MB each; nvs/otadata offsets are unchanged.
    Requires one USB upload to apply.
2026-09-28 Don't log NVS errors when reading OTA keys that aren't set yet
    [ota_update.cpp]
2026-09-28 Add throttled OTA test server; silence NVS remove of unset key
    tools/serve_ota.py replaces 'python -m http.server' for OTA tests and can
    throttle downloads so a mid-transfer server stop can be tested by hand.
    [ota_update.cpp]
2026-09-28 End serial log lines with CRLF to stop staircase output
    Serial.println already sends \r\n; the printf/embedded \n strings sent a bare
    LF, which some Windows terminals render without returning to column 0.
2026-09-28 Replace manifest OTA with ThingsBoard MQTT OTA
    - New tb_client module: one persistent MQTT-over-TLS connection to
    eu.thingsboard.cloud:8883 (CA bundle verified, token from secrets.h),
    rate-limited reconnect, on-connect hook. Messaging will reuse it.
    - ota_update.cpp now uses thingsboard-client-sdk 0.15.0: reads the
    assigned fw_title/fw_version, skips a version that previously rolled
    back (reports FAILED), otherwise runs Start_Firmware_Update with the
    Espressif_Updater. Rollback handling from Stage 1 is unchanged
    (verifyRollbackLater override + NVS ota/pending, ota/bad).
    - On every connect: report current_fw_title/current_fw_version as
    client attributes and telemetry; after an O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
    [main.cpp, ota_update.cpp, tb_client.cpp]
2026-09-28 Remove ArduinoOTA; restore platformio.ini comments
    ThingsBoard OTA is now the only over-the-air path; USB upload is the
    recovery path. Drops the esp32dev_ota env, ArduinoOTA/mDNS setup and
    loop handling (~54KB flash).
    platformio.ini lost its comments in 34555d6 because `pio pkg uninstall`
    rewrites the file; restored them and added a note to edit lib_deps by
    hand. README quick start updated to match.
2026-09-28 Set FIRMWARE_VERSION to 0.2.2 to match the deployed device
2026-09-29 Firmware: display mode manager (eye, clock, message history)
    - modes:: manager with EYE_ANIMATION / CURRENT_TIME / MESSAGE_HISTORY,
    each with its own render function; boots into the eye.
    - Eye animation moved to eye_mode.cpp unchanged; saved palettes are now
    a runtime theme (eye::setTheme, default Amber).
    - CURRENT_TIME: SNTP once WiFi is up (Tbilisi TZ), analog clock face;
    "NEED WIFI" / "SYNCING TIME" until the first sync.
    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
2026-09-29 Firmware 0.3.1: sharper scrolling text, single-LED clock hands, addMessage/reboot test RPCs
    [clock_mode.cpp, main.cpp, remote_test.cpp]
2026-09-29 Firmware 0.3.2: clock and text use true LED geometry (even-pitch disc)
    The clock face and scrolling text sampled ledCoords, which stretches every
    row to full width. Add panelCoords (even pitch) for screenPos(); the eye still
    uses ledCoords. Tweak clock colors, tick radius and text size to match.
2026-09-29 Firmware 0.3.3: fix vertical flip (SCREEN_Y_SIGN), tilt scrolling text onto the LED grid
2026-09-29 Firmware 0.3.5: full outer ring on the clock, ledTest wiring pattern RPC
2026-09-29 Firmware 0.3.6: raise RPC method limit to 8 (5 methods broke all RPCs in 0.3.5)
    [remote_test.cpp]
2026-09-29 Firmware 0.3.9: actually tilt the text, sample at pixel centers, 5x7 font, letters style by default
    The 0.3.3 tilt patch never applied (TEXT_COS/SIN were defined but unused), so
    all text was sampled upright on the diagonal LED grid. LED centers also sat on
    font pixel boundaries, so floating-point noise picked each LED's pixel.
2026-09-29 Firmware 0.4.0: keep tilted smooth scroll, strip CR/LF from messages, remove debug RPCs
    Drops ledTest / textStyle and the stepped and letter-by-letter text styles.
    Contract updated.
2026-09-29 Firmware 0.5.2: same as 0.5.1 (0.5.1 is flagged bad on the robot after an interrupted OTA)
2026-10-04 Decided to turn the screen 45 degrees, now text scrolling is upright instead of diagonal, will still need to turn eye animation sideways. The screen has physically turned, tradeoff is that its not fu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
